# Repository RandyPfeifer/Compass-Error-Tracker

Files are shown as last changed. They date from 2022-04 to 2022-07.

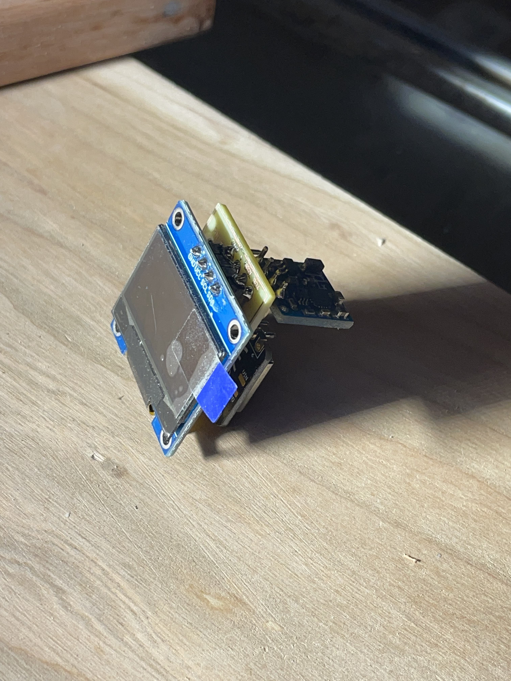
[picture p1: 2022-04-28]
Examples/Assembled2.JPG

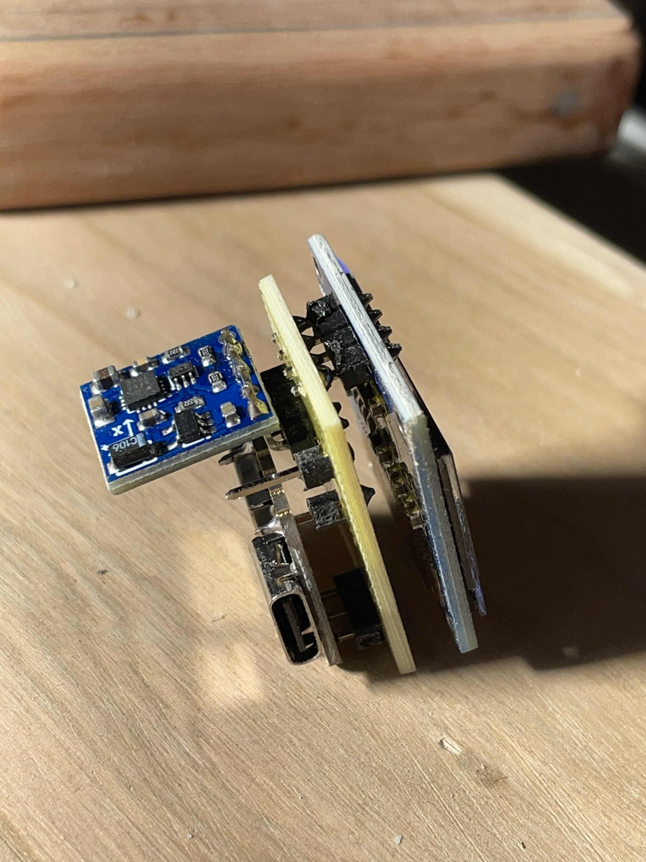
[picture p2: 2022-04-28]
Examples/Assembled1.JPG

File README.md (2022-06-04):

# Compass-Error-Tracker
Using a compass, GPS and small display, plot accumulated error (+/-) in your heading vs intended course

This project was undertaken to provide training experiences for canoe paddlers interested in improving their ability to paddle from Point A 
directly to Point B when they know the initial direction to B while sitting at A. It can also be used in the field when paddling in circumstances where 
visibility is impaired (i.e., fog) and a target is not readily visible while enroute.

The second purpose of this project was as a learning experience for myself as this is my first Arduino, MC5883L, SSD1306, NEO-6M and Github experience. 

The project utilized an Arduino compatible processor with I2C services to communicate with a MC5883L compass module to measure changes in direction 
as well as a SSD1306-based 128 x 64 pixel display to output onoing assessment of accumulated error.  The GPS module in play is the NEO-6M module using software serial for UART communication.Two specfic processors have been tested with this software:  Arduino Nano Every and Seeeduino XIAO.  The Nano was used during early development but most all testing and later development (GPS in particular) was done on the Seeeduino XIAO. 

When initialized (on power-up or reset or when the push_button is released), the system samples the immediate / current direction the craft is pointing (don't turn the system on until you are pointing where you want to go).  Note that all compass measurements taken are actually an average of 3 samples taken 300 ms apart to remove a bit of noise.  This bearing formed from 9 samples (3 reads of 3 samples each averaged) is then used as the intended (target) course.  The display will signal "TARGET ACQUIRED" when this is accomplished. 

Subsequent measurements on a periodic basis (2 - 3 seconds) are compared with the initially recorded target course.  
If a measurement is different from the initally captured target, that "Error" is displayed in the middle of the screen and accumulated with subsequent measurements.  
The accumulated error may grow or shrink depending on adjustments made by the person steering the craft. Ideally
they would strive to keep this accumulated error as small as possible without resorting to abrupt changes in direction (no sudden moves).

The overall accumulated Error (degree - seconds) is displayed graphically as a growing (or shrinking) 1/4 circle. The sign (+/-) of this accumulated
error is conveyed by which half of the screen the 1/4 circle is placed:

- 1/4 circle on right indicates the accumulated error has moved the craft to the right of intended course.
- 1/4 circle on the left indicates an accumulated error moving to the left of the intended course.

As the accumulated error grows or shrinks the radius of the 1/4 circle expands or contracts. As you move from the accumulated error being positive to negative, 
the 1/4 circle of interest flips to the other side of the display.

The intent would be for the user to adjust their steering to keep the circle radius as small as possible (ideally near zero). 

If the accumulated error grows beyond a defined threshold, the screen is updated to add a "turn signal" to the blank side of the screen.  For example, if the craft has strayed off to the right and a large 1/4 circle has grown on the right side of the screen, the left side of the screen will display a left turn signal.  Similarly for the opposite condition.  

Also, if the accumulated error grows beyond a certain (larger) threshold, the current cycle measured error number is displayed in Yellow and large Font to signal the need for more aggressive action to correct the error.

Further, if the accumulated error grows to an enormous threshold, the side of the screen reflecting that error will display the actual accumulated error to be "worked off" by steering in the appropriate direction indicated on the other side of the display. 

At any time, the button on the unit can be pressed which will effectively restart the process, taking a new target bearing and zeroing out the accumulated error. 

A short video of the program in operation (inside my house) can be found here:  https://youtu.be/wzSbLun69U0

## Notes

This system is unaware of effects of wind on the craft in motion.  As such, on windy days, "off course" conditions can be experienced even
if the accumulated error is maintained at zero. 

Similarly, this system is unaware of the speed of the craft and assumes a constant speed. 

Under the conditions of no wind (or other forces that would move the craft off course), and a constant speed, the display will provide a faithful indication of on/off course and a relative magnitued of the current off-course condition. 

There is some  code in there to account for the 32bit vs 16 bit differences between the processors and the fact that the measured samples from the compass module are 16 bit signed integers.

Schematic and board designs included in /src (created with Autodesk - Eagle).
A few pictures in /Examples. including a photo of a hand etched board and first assembled prototype and a link to a utube video of working system.

## GPS services

The unit also includes a GPS module.  Once it is in service and has a lock with a sufficient number of satellites, it will begin to deliver NMEA sentences with location (lat/lon), heading, speed, etc.  The software will switch to navigating using the GPS once certain criteria are met:

1. The paddler is within a certain cumulative error level (we want them to be close to their original intended line of travel)
2. The current heading is close to the intended heading identified at the beginning of the session (i.e., pointing in the right direction)

These criteria ensure that the craft is on the correct path (ignoring wind conditions referenced above) and GPS navigation can continue from there. 
After maintaining this criteria for a period of about 45 seconds, the GPS will derive a heading from its own readings and determine the heading target that the GPS will follow.
This avoids the need for the compass to produce a heading that is true to the real world (we only needed relative changes in direction from the compass to do all of our navigation so far). 

With that GPS-derived heading the software calculates the deviation from a line drawn from the point the GPS came into service (point A') in the direction of the GPS-derived target heading.  This deviation is now displayed as the cumulative error in the same fashion cumulative errors were displayed under compass navigation. The error displayed in the middle of the screen, which used to be the difference in current compass angle and the intended heading, is replaced with a new error which is the difference in current heading and the intended heading. Hence the meaning and interpretation of the display are consistent in Compass and GPS modes. 

In the upper right corner of the display will be an indicator of the status of the GPS module:
- !G - no GPS services are available
- ~G - the system is currently using valid GPS data and is in the 45+ second training cycle with the above criteria being met (this cycle may fail and need to be extended until the above criteria are met again - a flip back to !G).
- G! - the system has acheived all criteria for switching to GPS navigation and has made the transition. No further us of the compass is needed. 

When G! has been acheived, the upper left corner of the display shows the current heading reported by the GPS. 

Every 2-3 seconds, the GPS is polled for new information and the error calculation is repeated and the display updated.  The paddler can now be confident that no additional error can be introduced by effects of wind or current.  As long as GPS services remain, the system will continue to deliver accurate assessment of the overall divergence from the GPS derived heading.  

In order to eliminate any error in the GPS training cycle, the user can choose to explicitly provide the intended heading (in addition to pointing the craft in the proper direction when the system is powered up).   Even if GPS services are not available, the user can press the (reset) button on the unit and hold it down for an excess of 3 seconds.  This will signal the system to enter an "input" mode and it will display the current compass reading on the display.  The user can then rotate the unit to get the compass direction they are intending to travel on the display.  Once this is acheived, simply releasing the button will cause this last reading to be recorded for future use by the GPS.  Once the GPS comes online, the training process is circumvented and the system begins to immediatley navigate using the "input" target heading. 

The user could of course wait at their starting point for the GPS to be in service and perform all of their paddling under the guidance of the GPS.

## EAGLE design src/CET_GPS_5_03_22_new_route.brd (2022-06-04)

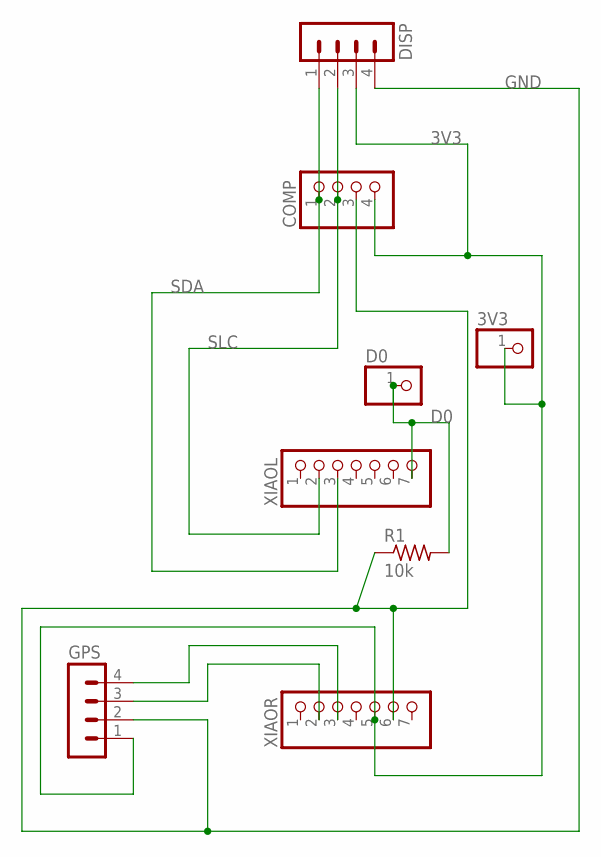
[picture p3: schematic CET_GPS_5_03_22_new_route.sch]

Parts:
3V3: PINHD-1X1; 1X01
COMP: PINHD-1X4/90; 1X04/90
D0: PINHD-1X1; 1X01
DISP: MA04-1
GPS: MA04-1
R1: 10k; 0204/7
XIAOL: PINHD-1X7; 1X07
XIAOR: PINHD-1X7; 1X07

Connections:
3V3: 3V3.1, COMP.4, DISP.3, GPS.1, XIAOR.5
D0: D0.1, R1.2, XIAOL.7
GND: COMP.3, DISP.4, GPS.2, R1.1, XIAOR.6
RX: GPS.3, XIAOR.2
SDA: COMP.1, DISP.1, XIAOL.3
SLC: COMP.2, DISP.2, XIAOL.2
TX: GPS.4, XIAOR.3

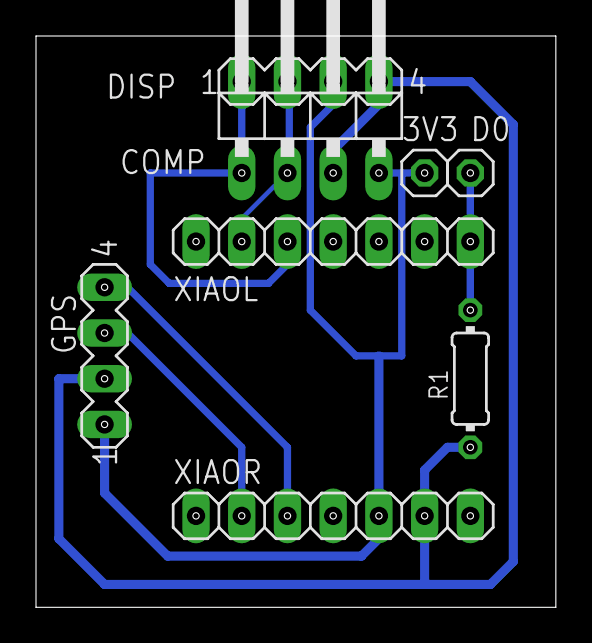
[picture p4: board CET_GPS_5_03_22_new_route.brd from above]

Board: 2 copper layers, 28.9 x 31.7 mm, 8 parts (0 on the bottom side), 7 nets.

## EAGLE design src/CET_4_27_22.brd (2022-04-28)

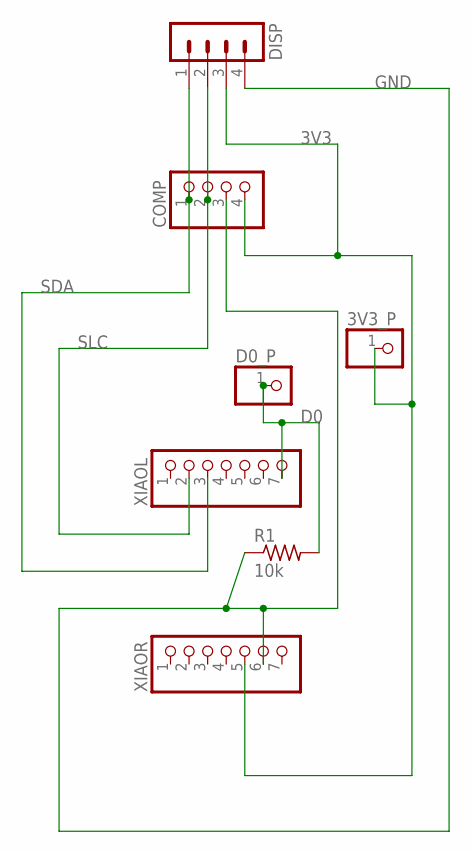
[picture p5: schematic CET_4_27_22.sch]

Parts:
3V3_P: PINHD-1X1; 1X01
COMP: PINHD-1X4/90; 1X04/90
D0_P: PINHD-1X1; 1X01
DISP: MA04-1
R1: 10k; 0204/7
XIAOL: PINHD-1X7; 1X07
XIAOR: PINHD-1X7; 1X07

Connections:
3V3: 3V3_P.1, COMP.4, DISP.3, XIAOR.5
D0: D0_P.1, R1.2, XIAOL.7
GND: COMP.3, DISP.4, R1.1, XIAOR.6
SDA: COMP.1, DISP.1, XIAOL.3
SLC: COMP.2, DISP.2, XIAOL.2

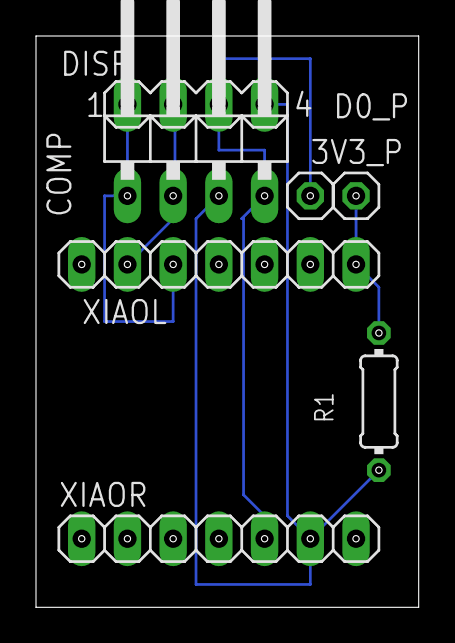
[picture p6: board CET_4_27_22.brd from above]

Board: 2 copper layers, 21.3 x 31.7 mm, 7 parts (0 on the bottom side), 5 nets.

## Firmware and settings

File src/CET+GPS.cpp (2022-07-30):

// Copyright (c) 2022, Randy Pfeifer
// All rights reserved.

/*
   Derived from review of: e-Gizmo QMC5883L GY-271 Compass

   Sample sketch for the GY-271 QMC5883L
   for getting the raw data of x, y, z and
   Radius in degrees.

   Codes by e-Gizmo Mechatronix Central
   http://www.e-gizmo.com
   July 10,2017

*/
/*********
  Also derived from review of:  Complete project details at https://randomnerdtutorials.com
  
  This is an example for our Monochrome OLEDs based on SSD1306 drivers. Pick one up today in the adafruit shop! ------> http://www.adafruit.com/category/63_98
  This example is for a 128x32 pixel display using I2C to communicate 3 pins are required to interface (two I2C and one reset).
  Adafruit invests time and resources providing this open source code, please support Adafruit and open-source hardware by purchasing products from Adafruit!
  Written by Limor Fried/Ladyada for Adafruit Industries, with contributions from the open source community. BSD license, check license.txt for more information All text above, and the splash screen below must be included in any redistribution. 
*********/

// This program utilizes the NeoGPS library and utilizes some lines of code from a couple Examples included with that library...

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
#include <SPI.h>
#include <Wire.h>
#include <Adafruit_GFX.h>
#include <Adafruit_SSD1306.h>

#include <NMEAGPS.h>
#include <SoftwareSerial.h>
static const int RXPin = 9, TXPin = 8;
static const uint32_t GPSBaud = 9600;
// The serial connection to the GPS device
SoftwareSerial gpsPort(RXPin, TXPin);
// The serial connection to the GPS device

#define GPS_Heading_Hurdle 15


#define SCREEN_WIDTH 128 // OLED display width, in pixels
#define SCREEN_HEIGHT 64 // OLED display height, in pixels

#define Cum_Error_Threshold 25 // start to display turn signals
#define ALARM_THRESHOLD 55 // increase font size and move error display to yellow line. 
#define HUGE_THRESHOLD 500 // display extra data when this cumulative error is reached. 
#define TURN_HEIGHT   38
#define TURN_WIDTH    38

// 'Go_Left', 38x38px
const unsigned char epd_bitmap_Go_Left [] PROGMEM = {
	0xff, 0xff, 0xff, 0xff, 0xfc, 0xff, 0xff, 0xff, 0xff, 0xfc, 0xff, 0xff, 0x8f, 0xff, 0xfc, 0xff, 
	0xff, 0x37, 0xff, 0xfc, 0xff, 0xfe, 0x7b, 0xff, 0xfc, 0xff, 0xfc, 0xfd, 0xff, 0xfc, 0xff, 0xf9, 
	0xfe, 0xff, 0xfc, 0xff, 0xf3, 0xff, 0x7f, 0xfc, 0xff, 0xe7, 0xff, 0xbf, 0xfc, 0xff, 0xcf, 0xff, 
	0xdf, 0xfc, 0xff, 0x9f, 0xff, 0xef, 0xfc, 0xff, 0x20, 0x07, 0xf7, 0xfc, 0xfe, 0x60, 0x07, 0xfb, 
	0xfc, 0xfc, 0xf0, 0x0f, 0xfd, 0xfc, 0xf9, 0xf0, 0x0f, 0xfe, 0xfc, 0xf3, 0xf0, 0x03, 0xff, 0x7c, 
	0xe7, 0xf8, 0x01, 0xff, 0xbc, 0xcf, 0xf8, 0x00, 0xff, 0xdc, 0xdf, 0xf8, 0x00, 0xff, 0xec, 0xdf, 
	0xfc, 0xe0, 0x7f, 0xec, 0xcf, 0xfc, 0xf0, 0x7f, 0xdc, 0xe7, 0xff, 0xf0, 0x7f, 0xbc, 0xfb, 0xff, 
	0xf0, 0x7f, 0x7c, 0xf9, 0xff, 0xf0, 0x7e, 0xfc, 0xfe, 0xff, 0xf0, 0x7d, 0xfc, 0xff, 0x7f, 0xf0, 
	0x7b, 0xfc, 0xff, 0x3f, 0xf0, 0x77, 0xfc, 0xff, 0xdf, 0xf0, 0x6f, 0xfc, 0xff, 0xef, 0xff, 0xdf, 
	0xfc, 0xff, 0xf7, 0xff, 0xbf, 0xfc, 0xff, 0xfb, 0xff, 0x7f, 0xfc, 0xff, 0xfd, 0xfe, 0xff, 0xfc, 
	0xff, 0xfe, 0xfd, 0xff, 0xfc, 0xff, 0xff, 0x7b, 0xff, 0xfc, 0xff, 0xff, 0xb7, 0xff, 0xfc, 0xff, 
	0xff, 0xcf, 0xff, 0xfc, 0xff, 0xff, 0xff, 0xff, 0xfc, 0xff, 0xff, 0xff, 0xff, 0xfc
};
// 'Go_Right', 38x38px
const unsigned char epd_bitmap_Go_Right [] PROGMEM = {
	0xff, 0xff, 0xff, 0xff, 0xfc, 0xff, 0xff, 0xcf, 0xff, 0xfc, 0xff, 0xff, 0xb7, 0xff, 0xfc, 0xff, 
	0xff, 0x7b, 0xff, 0xfc, 0xff, 0xfe, 0xfd, 0xff, 0xfc, 0xff, 0xfd, 0xfe, 0xff, 0xfc, 0xff, 0xfb, 
	0xff, 0x7f, 0xfc, 0xff, 0xf7, 0xff, 0xbf, 0xfc, 0xff, 0xef, 0xff, 0xdf, 0xfc, 0xff, 0xdf, 0xff, 
	0xef, 0xfc, 0xff, 0xbf, 0x80, 0x17, 0xfc, 0xff, 0x7f, 0x00, 0x3b, 0xfc, 0xfe, 0xff, 0x80, 0x3d, 
	0xfc, 0xfd, 0xff, 0xc0, 0x3e, 0xfc, 0xfb, 0xff, 0x00, 0x7f, 0x7c, 0xf7, 0xfe, 0x00, 0x7f, 0xbc, 
	0xef, 0xfc, 0x00, 0x7f, 0xdc, 0xdf, 0xfc, 0x08, 0xff, 0xec, 0xdf, 0xf8, 0x18, 0xff, 0xec, 0xef, 
	0xf8, 0x3d, 0xff, 0xdc, 0xf7, 0xf8, 0x3f, 0xff, 0xbc, 0xfb, 0xf8, 0x3f, 0xff, 0x7c, 0xfd, 0xf8, 
	0x3f, 0xfe, 0xfc, 0xfe, 0xf8, 0x3f, 0xfd, 0xfc, 0xff, 0x78, 0x3f, 0xfb, 0xfc, 0xff, 0xb8, 0x3f, 
	0xf7, 0xfc, 0xff, 0xd8, 0x7f, 0xef, 0xfc, 0xff, 0xef, 0xff, 0xdf, 0xfc, 0xff, 0xf7, 0xff, 0xbf, 
	0xfc, 0xff, 0xfb, 0xff, 0x7f, 0xfc, 0xff, 0xfd, 0xfe, 0xff, 0xfc, 0xff, 0xfe, 0xfd, 0xff, 0xfc, 
	0xff, 0xff, 0x7b, 0xff, 0xfc, 0xff, 0xff, 0xb7, 0xff, 0xfc, 0xff, 0xff, 0xcf, 0xff, 0xfc, 0xff, 
	0xff, 0xff, 0xff, 0xfc, 0xff, 0xff, 0xff, 0xff, 0xfc, 0x00, 0x00, 0x00, 0x00, 0x00
};

// Array of all bitmaps for convenience. (Total bytes used to store images in PROGMEM = 416)
const int epd_bitmap_allArray_LEN = 2;
const unsigned char* epd_bitmap_allArray[2] = {
	epd_bitmap_Go_Left,
	epd_bitmap_Go_Right
};


// Declaration for an SSD1306 display connected to I2C (SDA, SCL pins)
#define OLED_RESET     -1 // Reset pin # (or -1 if sharing Arduino reset pin)
Adafruit_SSD1306 display(SCREEN_WIDTH, SCREEN_HEIGHT, &Wire, OLED_RESET);



#include <QMC5883L.h>

QMC5883L compass;


NMEAGPS gps;
gps_fix fix;



//some global variables...
bool Start_flag = true;
bool BAT = false;
float TARGET=777;
float Error=77;
float Cumulative_Error = 0;
int GPS_Ready = 1;  // don't declare GPS mode until we have "GPS_Heading_Hurdle" valid sentences in a row. 
bool GPS_flag = false;  // Signal for GPS switch-over.
float GPS_Heading=0;
float REAL_TARGET=0;
bool REAL_TARGET_Flag=false;
float Measurement=0;
float New_Point_A_lat=0;
float New_Point_A_lon=0;
float Bearing_from_A_prime=0;
float Bearing_to_A_prime=0;
float Error_Angle=0;

void setup() {
 
  Wire.begin();     
  Serial.begin(9600);  
  gpsPort.begin(GPSBaud);
  compass.init();     
  //while(!Serial);
  
 
 //qmc.setMode(Mode_Continuous,ODR_200Hz,RNG_2G,OSR_256);
 // SSD1306_SWITCHCAPVCC = generate display voltage from 3.3V internally
  if(!display.begin(SSD1306_SWITCHCAPVCC, 0x3C)) { 
    Serial.println(F("SSD1306 allocation failed"));
    for(;;); // Don't proceed, loop forever
  }

  // Show initial display buffer contents on the screen --
  // the library initializes this with an Adafruit splash screen.
  display.display();  // Display splash..

/* use the following to lower the brightness of the display - seems too dim for outdoor use though...
  display.ssd1306_command(0x81);  // point to contrast setting parameter
  display.ssd1306_command(0);     // set contrast to minimum value. 
  display.ssd1306_command(0xD9);   // point to pre-charge parameter
  display.ssd1306_command(0x11);   // set to minimum value for both phase 1 and phase 2
*/

delay(500); // Pause for .5 seconds to display splashscreen
 
  // Clear the display buffer
  display.clearDisplay();

  // set up Pin D0 as an input for a pushbutton. May be used someday.... Pulled down with 10K resistor.
  pinMode(0,INPUT);
    
  REAL_TARGET_Flag=false;

}

void loop() {

int Button = digitalRead(0);
  if (Start_flag || Button) {  //Sample target heading on first pass through the loop or anytime the button is pressed
  unsigned long time = millis();
    while (Button) {
      if (!BAT) Serial.println("BUTTON PUSHED");
      display.clearDisplay();
      display.setCursor(0,0);
      display.setTextSize(2);
      display.setTextColor(WHITE,BLACK);
      display.println("BUTTON");
      display.println("PUSHED");
      if (millis() >= (time+2000)) { // long hold on button - initiate recording of heading for GPS later
        REAL_TARGET = read3();
        REAL_TARGET_Flag=true;
        display.println(REAL_TARGET,0);
      }
      display.display();
      /* Don't reset flag if previously set - keep REAL_TARGET setting even if button is short-pushed later.  
      This will allow user to short-push button to initiate compass-based navigation until GPS is online.  
      Only a power-cycle will reset REAL_TARGET_Flag to flase. 
      
      else {
       // REAL_TARGET_Flag=false;   
      }
      */

      delay(600);
      Button = digitalRead(0);
    }

    if (!BAT) Serial.print("   Reading TARGET ");
    display.setCursor(0,0);
    display.setTextSize(2);
    display.setTextColor(WHITE,BLACK);
    display.println("ACQUIRING");
    display.println("TARGET");
    display.display();
    delay(1000);
    TARGET = (read3() + read3() + read3()) / 3;  // read 9 samples and average them.   NOTE!: this code doesn't account for the 0/360 boundary properly

    Cumulative_Error=0; 

    // Signal on the display that we have a target to use.     
    display.clearDisplay();
    display.setCursor(0,20);
    display.println("TARGET");
    display.println("ACQUIRED!");
    display.display();
    Start_flag = false;  // don't do the above again unless reset button is pushed. 
    GPS_flag = false;  // start with Compass navigation (reset to false if button is pushed)
    GPS_Ready = 1;
    delay(600);  // get ready for cycles of measurements to assess error from target course.
  }

if(!GPS_flag) { // navigate using the compass
  // read 3 compass samples averaged to get current heading.
  Measurement = read3();

  Error = Measurement - TARGET;
   // look for 360 degree wrap around and correct if ncessary  before accumulating error.
  if (Error > 180)
        Error -= 360.0;
  if (Error < -180)
        Error += 360.0;

  Cumulative_Error += Error;  // accumulate overall error

}
else { // GPS_flag must be true.  Navigate using the GPS...
// still grab compass direction and update Measurement
Measurement = read3(); //for no particular reason other than debug printing and consistent loop timing...

/* calculate  the total +/- deviation from the intended course - assign that to Cumulative_Error
this calculation should be based on distance from Point_A and the angle deviation from TARGET
*/
// The base location (A_prime), in degrees * 10,000,000???
NeoGPS::Location_t A_prime( New_Point_A_lat, New_Point_A_lon ); // the new Point_A
float D = fix.location.DistanceMiles( A_prime )* 5280; //Distance to Point_A in feet.
Bearing_to_A_prime = fix.location.BearingToDegrees(A_prime);

// calclate reverse bearing (bearing from A prime)
if (Bearing_to_A_prime >180)
   Bearing_from_A_prime = Bearing_to_A_prime -180;
  else
   Bearing_from_A_prime = Bearing_to_A_prime +180;

Error_Angle=Bearing_from_A_prime-TARGET; // calculate current diff in  the angle of current position vs Target
// correct for 0/360 degree border issues. 
if (Error_Angle > 180)
  Error_Angle -= 360;
if (Error_Angle <-180)
  Error_Angle += 360;
Serial.println();
Serial.print("Bearing to / from A prime=  ")/
Serial.print(Bearing_to_A_prime);
Serial.print("  /   ");
Serial.print(Bearing_from_A_prime);
Serial.print(" Error_Angle = ");
Serial.print(Error_Angle);
Serial.print(" D= ");
Serial.println(D);


  // Calculate the distance we are off from the Target course. 
Cumulative_Error=D*sin(Error_Angle*PI/180); 
/*
calculate the current course angle minus the TARGET heading - assign to Error.
this calculation should be based on current heading compared with TARGET
*/
Error = fix.heading() - TARGET;  

 // look for 360 degree wrap around and correct if ncessary
  if (Error > 180)
        Error -= 360.0;
  if (Error < -180)
        Error += 360.0;
}


// display target/measurment/error/Cumulative_Error calculated by either compass or GPS.
if (!BAT) {
  Serial.print("Target: ");
  Serial.print(TARGET);
  Serial.print(",Measurement: ");
  Serial.print(Measurement);
  Serial.print(",Error: ");
  Serial.print(Error);
  Serial.print(",Cumulative Error: ");
  Serial.println(Cumulative_Error);
}
// Updat display with error, cumulative error, graphics for steering, etc once per loop
Update_Display();  


// Sample GPS information 

//Allow GPS parser a full 1.5 seconds to get at least one fix
unsigned long time = millis();
while (millis() <= (time+1500)) {
    while (gps.available( gpsPort )) {
    fix = gps.read();
    bool  validDT         = fix.valid.date & fix.valid.time;

    print(             fix.satellites       , fix.valid.satellites, 3             );
  //  print(             fix.hdop/1000.0      , fix.valid.hdop      , 6, 2          );
    print(             fix.latitude ()      , fix.valid.location  , 10, 6         );
    print(             fix.longitude()      , fix.valid.location  , 11, 6         );
    print(             fix.dateTime         , validDT             , 20            );
    print(             fix.altitude ()      , fix.valid.altitude  , 7, 2          );
    print(             fix.speed_kph()      , fix.valid.speed     , 7, 2          );
    print(             fix.heading  ()      , fix.valid.heading   , 7, 2          );
    print( gps.statistics.chars , true, 10 );
    print( gps.statistics.ok    , true,  6 );
    print( gps.statistics.errors, true,  6 );
    Serial.println();
 
 }

} // end of 1500 ms GPS phase for this cycle. Let's see how we did...

// Look for a string of good heading fixes IFF we are close to Compass-based guidance (low Error & Cum_Error)
Check_for_FIX();

 if (GPS_Ready > GPS_Heading_Hurdle && !GPS_flag) {// record GPS ready for use!!
   GPS_flag=true;  // we're done with the GPS acquisition phase (shorter phase if REAL_TARGET was assigned via long push)

   // assign new target for GPS navigation. 
    if (REAL_TARGET_Flag)
      TARGET = REAL_TARGET; // Use this if Long BUTTON PUSH was used to provide the actual target heading.
      else 
       TARGET = GPS_Heading;  // Use this if REAL_TARGET wasn't set via long BUTTON PUSH.
   New_Point_A_lat = fix.latitude();
   New_Point_A_lon = fix.longitude();
   Serial.println();
   Serial.print("Switching to GPS Mode!   New_Target=");
   Serial.print(TARGET);
   Serial.print(" Point A' = ");
   Serial.print(New_Point_A_lat,6);
   Serial.print("  /  ");
   Serial.println(New_Point_A_lon,6);
   Serial.println();

 }

}  // End of Loop




float Update_Display() {  // routine to display messages on OLED display

// draw a "upper half" circle whose radius reflects the overall size of accumulated error
  display.clearDisplay();
  int radius = int(fabs(Cumulative_Error))+7;  // why +7?  Don't let radius get too small - always want something visible
  display.fillCircle(SCREEN_WIDTH/2,SCREEN_HEIGHT-1,radius,WHITE);
  
  // if accumulated error is postive, wipe out left half of screen. Otherwise wipe out right half.  This produces a 1/4 circle. 
  if (Cumulative_Error >= 0) {
    display.fillRect(0,0,display.width()/2,display.height(),BLACK);
    // draw left turn sign on left side of screen if the accumulated error is larger than a threshold. 
    if (Cumulative_Error > Cum_Error_Threshold) display.drawBitmap(
    (display.width()/2  - TURN_WIDTH ) / 2,
    (display.height() - TURN_HEIGHT) / 2+10,
    epd_bitmap_Go_Left, TURN_WIDTH, TURN_HEIGHT, 1);
  }    
  else { // accumulated error is zero or negative
    display.fillRect(display.width()/2,0,display.width()/2,display.height(),BLACK);
    // draw right turn on right side of screen.
    if (Cumulative_Error < -Cum_Error_Threshold) display.drawBitmap(
    (display.width()/2  + TURN_WIDTH/2),
    (display.height() - TURN_HEIGHT) / 2+10,
    epd_bitmap_Go_Right, TURN_WIDTH, TURN_HEIGHT, 1);
  }

    // Draw a vertical line to bisect the display to make left/right error more clear.
    display.drawLine(SCREEN_WIDTH/2,SCREEN_HEIGHT/4+4,SCREEN_WIDTH/2,SCREEN_HEIGHT-1,WHITE);
  
  // Display current cycle Error amount.  If cumulative error is large, raise to yellow portion of screen.
    display.setTextSize(1); // Draw 1X-scale text
    display.setTextColor(WHITE,BLACK);
   
    if (fabs(Cumulative_Error) >= ALARM_THRESHOLD){
      display.setTextSize(2); // Draw 2X-scale text
      display.setCursor(display.width()/2-10, 0); // draw on top (yellow) line w/tweak to start of text to center on screen
    }
    else {
      display.setTextSize(1); 
      display.setCursor(display.width()/2-6,16); // draw smaller text on 2nd line
    }

    display.println(int(Error*10));  // simplify expression of error to (usually)single digit by multiplying by 10 and making an int.
    
// If cumulaltive error is huge display the cumulative error amount in the big blue square right or left.
  if (Cumulative_Error >= HUGE_THRESHOLD) {   // write cumulaltive error on right side
    display.setTextSize(2); 
      display.setCursor(display.width()/2+6,30);
      display.println(int(Cumulative_Error));
  }

  if (Cumulative_Error <= -HUGE_THRESHOLD) {  // write cumulative error on the left side.
    display.setTextSize(2);
      display.setCursor(2,30);
      display.println(int(Cumulative_Error));
    }

    // Display GPS status
    
    display.setTextSize(1);
    display.setCursor(display.width()-12,0);
    if (GPS_flag){
       display.print("G!"); // now using GPS
       display.setCursor(0,0);
       display.setTextSize(2);  // test with heading in larger font....
       display.println(fix.heading(),0); //display current heading
    }       
    else {
    if (GPS_Ready>1)
      display.println("~G");  // GPS is "in training"
      else
      display.println("!G"); // No GPS data available yet.
    }
    //Refresh screen for current cycle
    display.display(); // send it. 
 
 } //end of Update_Display()


float read3() {
   int x, y, z, x1, y1, z1, x2, y2, z2; // these are 4 byte entities on Seeeduino XIAO
   
   short sx, sy, sz, sx1, sy1, sz1, sx2, sy2, sz2; // compass will deliver 2 byte entities (signed)

   //int16_t sx, sy, sz, sx1, sy1, sz1, sx2, sy2, sz2; // compass will deliver 2 byte entities (signed)

   // take 3 samples 300ms apart
   compass.read(&x, &y, &z);
   delay(200);
   compass.read(&x1, &y1, &z1);
   delay(200);
   compass.read(&x2, &y2, &z2);
   delay(200);

   //convert all samples to 16bit signed numbers
  sx=x; sx1=x1; sx2=x2;
  sy=y; sy1=y1; sy2=y2;
  sz=z; sz1=z1; sz2=z2;
  
   // average the three samples to remove a bit of noise. 
   sx=(sx+sx1+sx2)/3;
   sy=(sy+sy1+sy2)/3;
   sz=(sz+sz1+sz2)/3;

   // Calculate heading when the magnetometer is level, then correct for signs of axis.
   // Atan2() automatically check the correct formula taking care of the quadrant you are in
   float heading = atan2(-sx, sy);

   // Correct for when signs are reversed.
   if (heading < 0)
    heading += 2 * PI;

   // Convert radians to degrees for readability.
   float Degrees = heading * 180 / PI;
 if (!BAT) {
   Serial.print("  x: ");
  // Serial.print(x);
  Serial.print(sx);
  //Serial.print(x2);
   Serial.print(",y: ");
  // Serial.print(y);
  Serial.print(sy);
  // Serial.print(y2);
   Serial.print(",z: ");
  // Serial.print(z);
   //Serial.print(z1);
   Serial.print(sz);
 }
   return Degrees;
 } // End of Read3()


 // Look for a string of good heading fixes IFF we are close to Compass-based guidance (low Error & Cum_Error)
float Check_for_FIX() {   //           V <<< Evaluate sizes of >>>  V 
 /* this routine calculates the average of a series of headings.  It might be much easier (and maybe more accurate)
 to simply calculate a course from the lat/lon at beginning and end of this loop (GPS_Ready=1 -> 15) 
 */
 
  if (fix.valid.location && abs(Error)<5 && abs(Cumulative_Error) < 20  && !GPS_flag && GPS_Ready <=GPS_Heading_Hurdle)  {  //   <<<<<<---------- (change to check for fix.valid.heading for real code)
      //         ^^^^^    calculate average heading so far
      if (GPS_Ready == 1) 
          GPS_Heading = fix.heading();  //first one stands alone...
          else {
          if (abs(fix.heading()-GPS_Heading) >= 330) { // deal with 360/zero wrap).
            if (fix.heading() < 30) // this sample is on the + side of 360. GPS_Heading must be just under 360
              GPS_Heading = (GPS_Heading * (GPS_Ready-1) + fix.heading()+360) / GPS_Ready;
              else  // this sample is on the - side of 360 & GPS_Heading must be above 0.
                GPS_Heading = ((GPS_Heading+360) * (GPS_Ready-1) + fix.heading()) / GPS_Ready;
                
          }
          else  // not a 360/0 border issue calculate average as usual
            GPS_Heading = (GPS_Heading * (GPS_Ready-1) + fix.heading()) / GPS_Ready;
          }
      if (GPS_Heading>360)  // Correct for over 360 condition on current average.
        GPS_Heading -= 360;  

        Serial.println();
        Serial.print("GPS_Ready= ");
        Serial.print(GPS_Ready);
        Serial.print(" GPS_Heading= ");
        Serial.print(GPS_Heading,3);
        Serial.print(" fix.heading= ");
        Serial.println(fix.heading());
        GPS_Ready=GPS_Ready+1;  // Get ready for next cycle.

    }
    else { // one or more conditions (i.e., error, Cum_error, valid fix) has failed
      GPS_Ready=1;  // reset hurdle condition - restart if we miss one or not close to Compass derived line.
     // GPS_flag=false; 
      GPS_Heading = 0;
    }
    
    if (fix.valid.location && REAL_TARGET_Flag)  // <<<<<< Changed to .heading
      GPS_Ready=GPS_Heading_Hurdle+1;  // don't waste time calculating an average heading if you already have a heading. 
} // End of Check_for_FIX


//-----------------
//  Print utilities

static void repeat( char c, int8_t len )
{
  for (int8_t i=0; i<len; i++)
    Serial.write( c );
}

static void printInvalid( int8_t len )
{
  Serial.write( ' ' );
  repeat( '*', abs(len)-1 );
}

static void print( float val, bool valid, int8_t len, int8_t prec )
{
  if (!valid) {
    printInvalid( len );
  } else {
    char s[16];
    dtostrf( val, len, prec, s );
    Serial.print( s );
  }
}

static void print( int32_t val, bool valid, int8_t len )
{
  if (!valid) {
    printInvalid( len );
  } else {
    char s[16];
    ltoa( val, s, 10 );
    repeat( ' ', len - strlen(s) );
    Serial.print( s );
  }
}

static void print( const __FlashStringHelper *str, bool valid, int8_t len )
{
  if (!valid) {
    printInvalid( len );
  } else {
    int slen = strlen_P( (const char *) str );
    repeat( ' ', len-slen );
    Serial.print( str );
  }
}
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

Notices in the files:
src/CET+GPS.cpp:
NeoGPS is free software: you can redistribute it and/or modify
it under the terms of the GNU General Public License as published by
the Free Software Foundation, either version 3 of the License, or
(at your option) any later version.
